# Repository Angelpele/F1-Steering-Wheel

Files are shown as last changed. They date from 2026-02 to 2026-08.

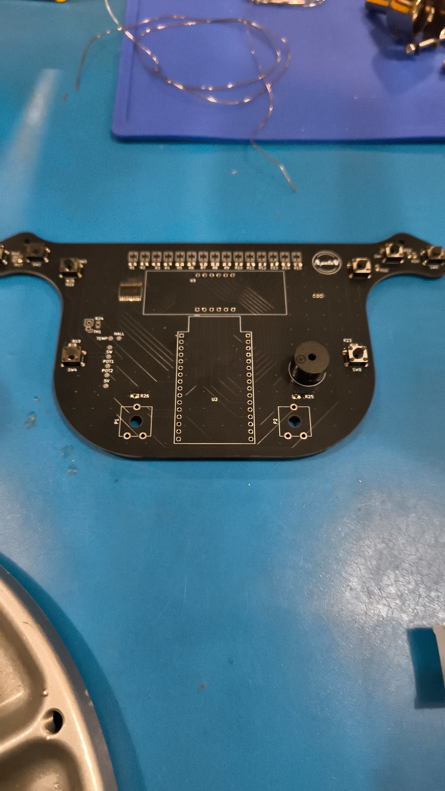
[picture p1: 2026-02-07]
Media/IMG-20260202-WA0003.jpeg

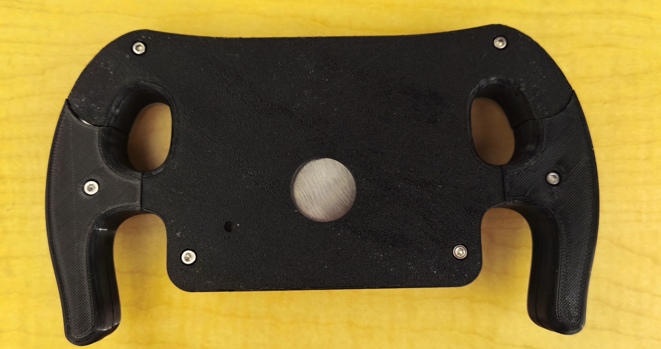
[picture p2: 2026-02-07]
Media/MVIMG_20260207_000938.jpg

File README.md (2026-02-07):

# 🏎️ F1 Steering Wheel

This project is a **custom-made F1-style steering wheel** designed and built entirely from scratch, featuring a **custom PCB**, advanced input/output handling, and a rigid mechanical structure optimized for sim racing or small racing karts.

<p align="center">
  
</p>

---

## 🛠️ Electronics & PCB Design

The steering wheel is built around a **custom-designed PCB** using an **ESP32-C6 DevKitC-1** as the main controller, providing high performance and wireless capabilities.

### Main Electronic Features

| Component | Description |
|---|---|
| **ESP32-C6 DevKitC-1** | Main microcontroller handling inputs, logic, and communication |
| **74LS154 Decoder** | 4-to-16 line decoder used to drive LED array |
| **15 LEDs (RGB Groups)** | Divided into 3 groups of 5 LEDs (Green, Red, Blue) |
| **4-Digit 7-Segment Display** | Displays speed, gear, or system information |
| **8 Buttons (Resistor Ladder)** | All buttons read through a single ADC pin |
| **2 Potentiometers** | Center mounted, using voltage divider for analog input |
| **Buzzer** | Return sound feedback to the user reacting to different variables |
| **External Sensor Support** | Designed for external NTC temperature sensor and Hall-effect sensor inputs|
| **Custom Buttons PCB** | Top-mounted buttons integrated into the housing |

<p align="center">
  
</p>

The **15 LEDs**, controlled via the **74LS154 decoder**, provide real-time visual feedback:
- **Green LEDs** → Speed or system status  
- **Red LEDs** → Engine RPM / rev-up indication  
- **Blue LEDs** → Custom functions or gear indicators  

The decoder uses **4 control lines** to efficiently manage all LED outputs.

The **8 buttons** are arranged with a resistor ladder configuration, reading all the possible values with an ADC converter (analog input).

📄 Find the **Circuit Schematic** right below:

<p align="center">
  <a href="Hardware/Volante Maquinillo.pdf">
    Electronics Schematic
  </a>
</p>

---

## ⚙️ Mechanical Design

The entire mechanical structure was **designed from scratch in Fusion 360**, prioritizing rigidity, modularity, and professional finish.

<p align="center">
  
</p>

### Structural Overview

1. **Lower Case**
   - Houses most electronic components.
   - Rear sockets allow bolts to be inserted flush with the surface.
   - Enables clean and solid assembly.

2. **Steel Reinforcement Plate**
   - Water-jet cut steel middle plate.
   - Provides structural rigidity and torsional strength.
   - Acts as the main load-bearing core.

3. **TPU Handles**
   - Designed in **two parts per side**.
   - Bolted directly to the internal steel structure.
   - Flexible yet durable for comfortable grip.

4. **PCB Mounting**
   - Custom PCB is mounted on top of the steel plate.
   - Electrically isolated to prevent short circuits.
   - Secured using threaded inserts.

5. **Top Case & Buttons**
   - Top enclosure holds the custom-made buttons.
   - Assembled using **threaded inserts melted into the plastic**.
   - All components are bolted together for maximum durability.

---

## 🚀 Project Goals

- Realistic **F1-style input device**
- Robust **mechanical and electrical integration**
- Support for additional external sensors
- Internal steel structure for proper soldering to external axes

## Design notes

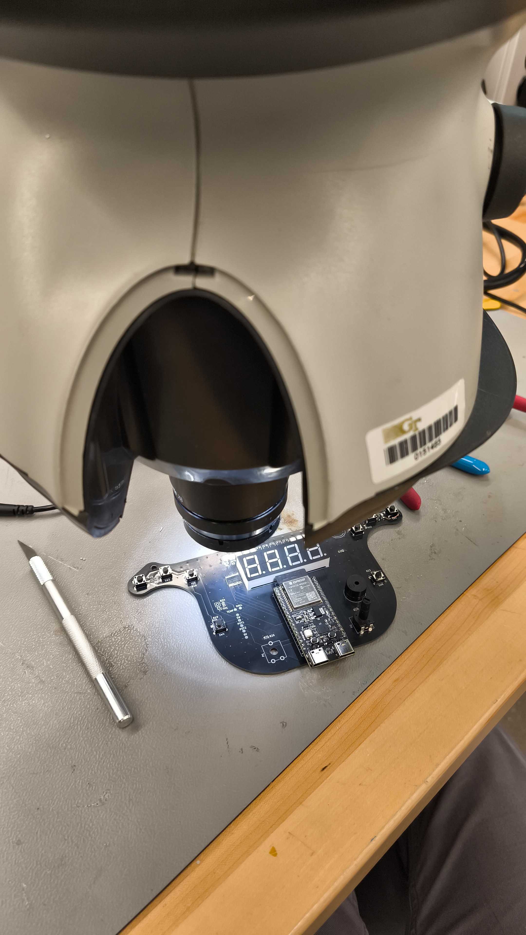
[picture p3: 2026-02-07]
Media/IMG-20260206-WA0000.jpeg

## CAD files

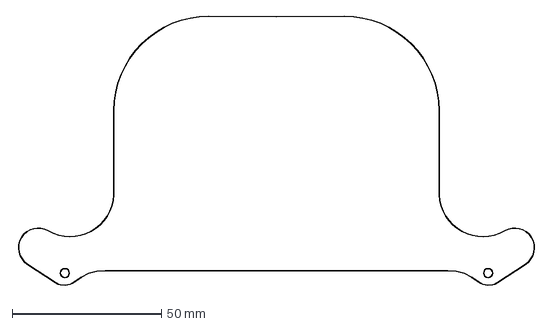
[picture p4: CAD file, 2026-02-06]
Mechanical/Main_DXF.dxf
174.4 x 90.5 mm

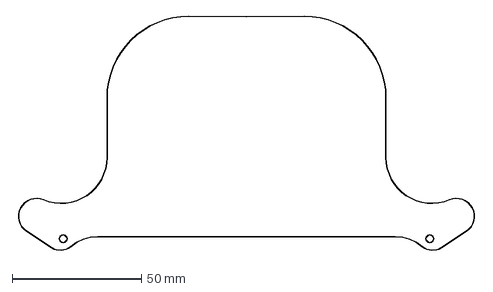
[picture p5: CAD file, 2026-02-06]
Mechanical/Main_PCB.dxf
177.8 x 90.9 mm

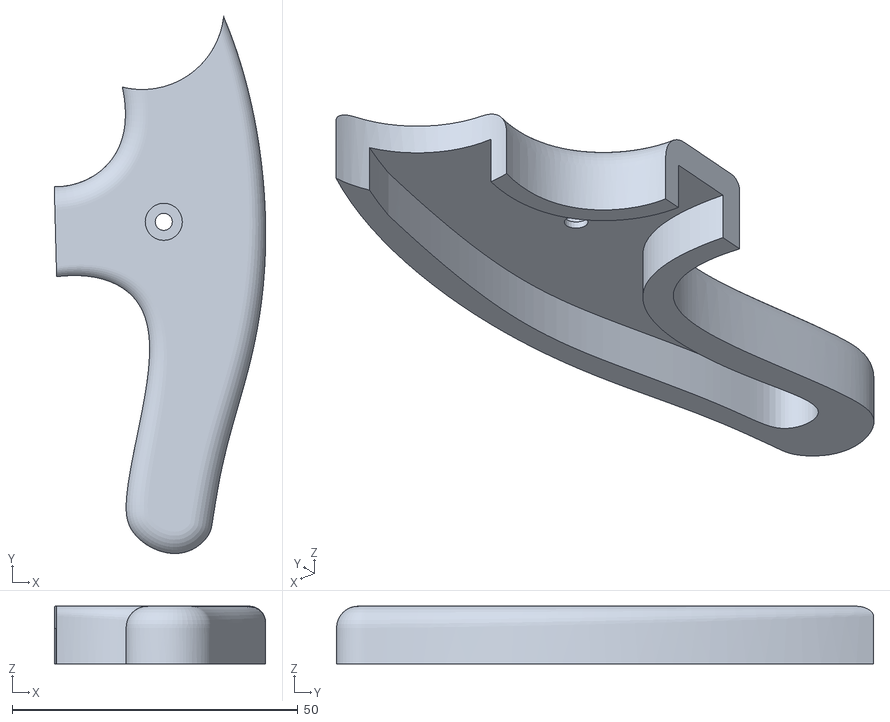
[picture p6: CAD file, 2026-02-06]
Mechanical/Left_Grip_Inf.stl
37.0 x 94.0 x 10.1

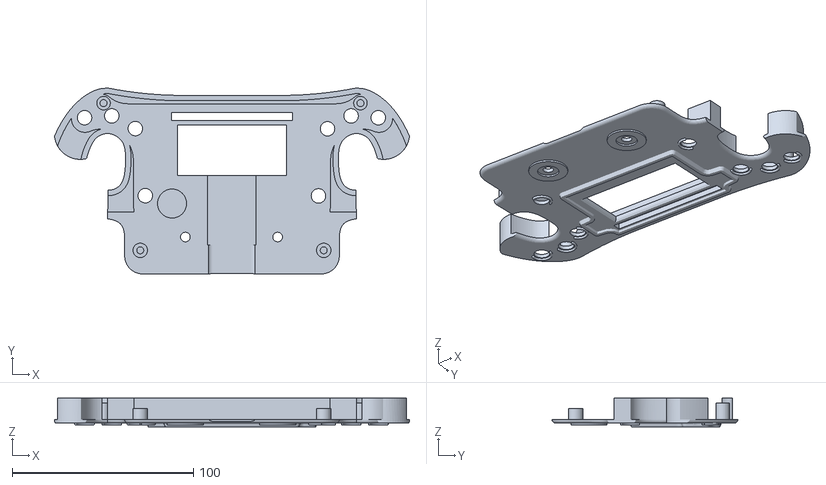
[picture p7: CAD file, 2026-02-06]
Mechanical/Top_Case.stl
195.8 x 102.5 x 15.8

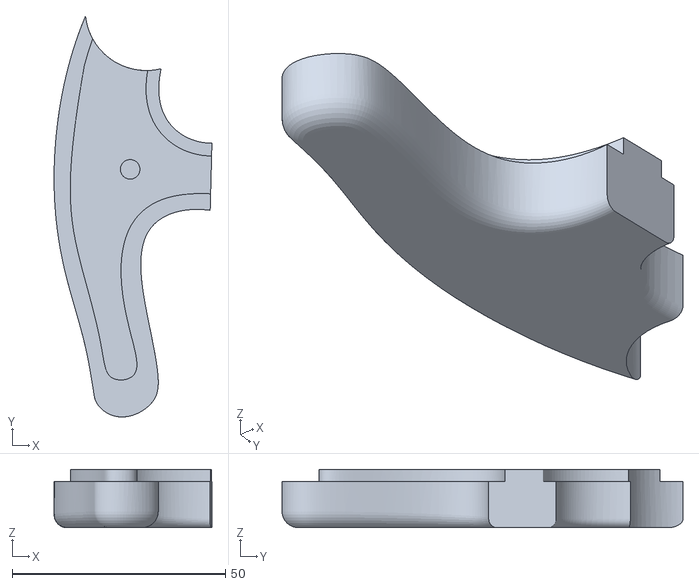
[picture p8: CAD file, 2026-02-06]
Mechanical/Right_Grip_Sup.stl
37.0 x 94.0 x 13.7

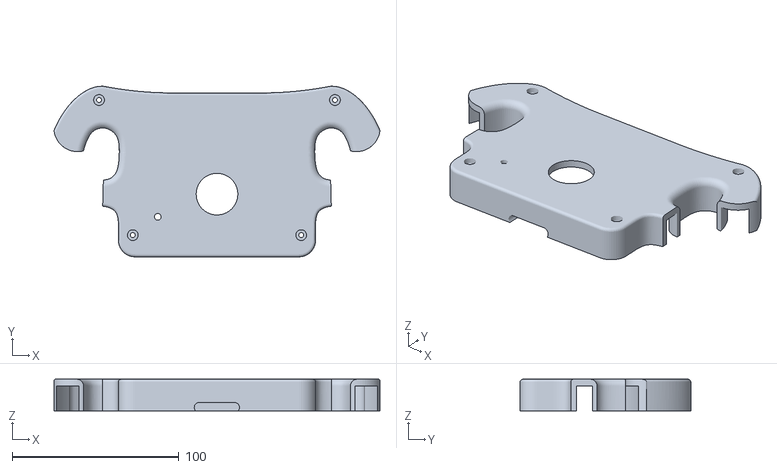
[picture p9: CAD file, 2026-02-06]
Mechanical/Bottom_Case.stl
195.8 x 102.5 x 19.0

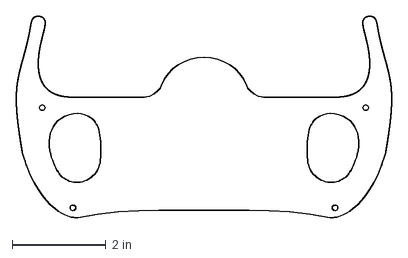
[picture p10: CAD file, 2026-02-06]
Mechanical/Al_Struct.dxf
7.99 x 4.29 in

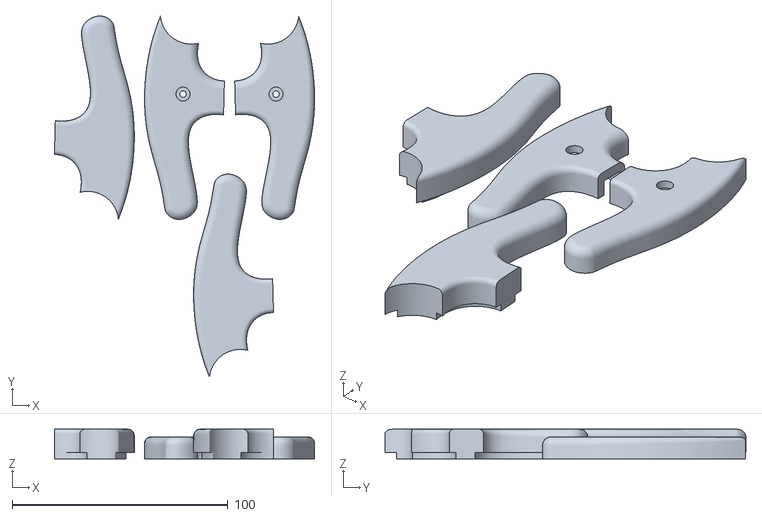
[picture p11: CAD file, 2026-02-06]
Mechanical/Grips.stl
120.5 x 167.2 x 13.7

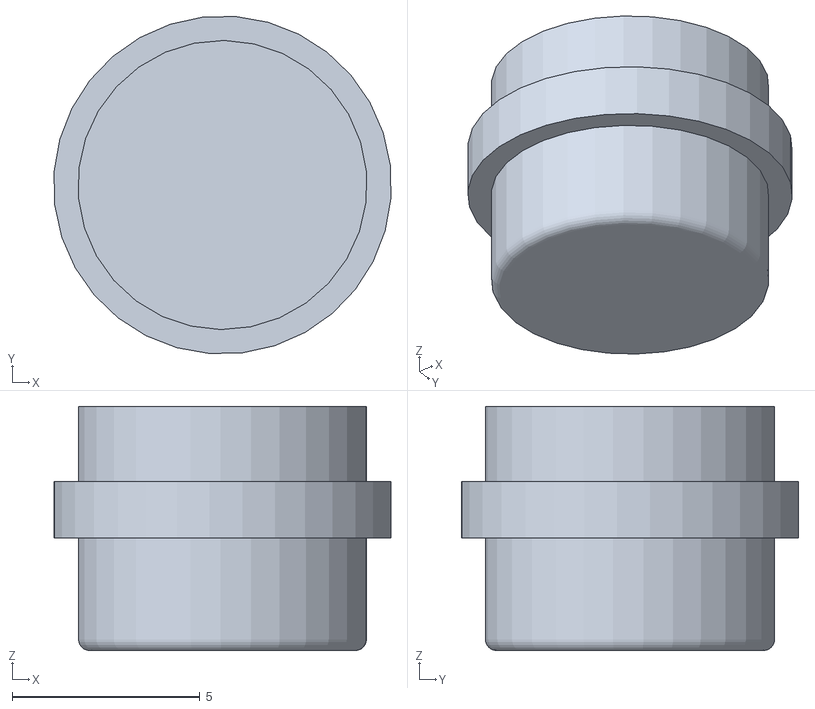
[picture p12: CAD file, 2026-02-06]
Mechanical/Button.stl
8.97 x 8.97 x 6.50

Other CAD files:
Mechanical/Left_Grip_Sup.stl
Mechanical/Right_Grip_Inf.stl

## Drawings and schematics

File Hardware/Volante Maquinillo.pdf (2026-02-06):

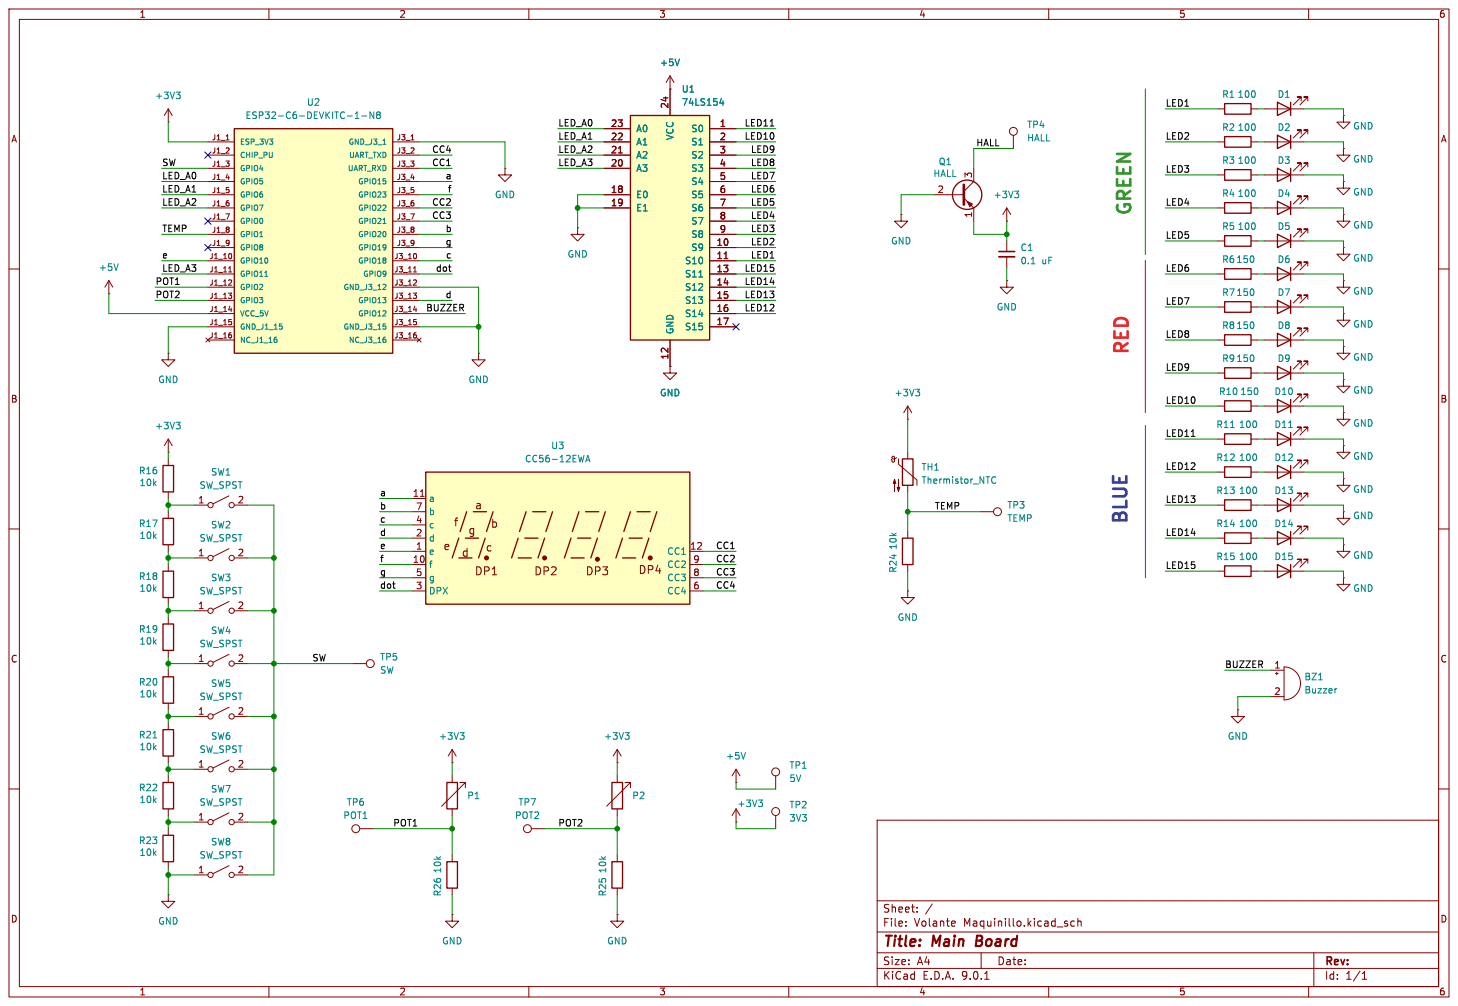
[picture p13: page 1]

Id: 1/1 Title: Main Board

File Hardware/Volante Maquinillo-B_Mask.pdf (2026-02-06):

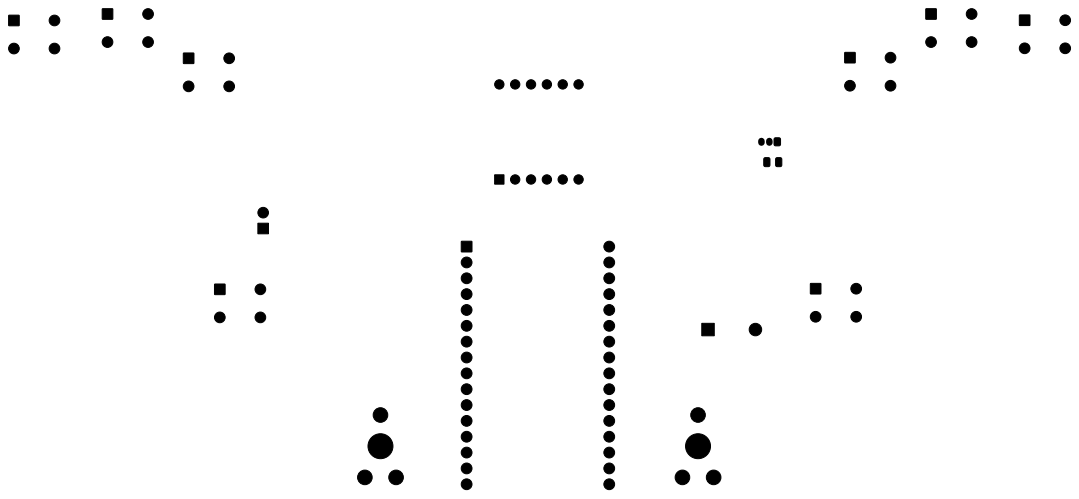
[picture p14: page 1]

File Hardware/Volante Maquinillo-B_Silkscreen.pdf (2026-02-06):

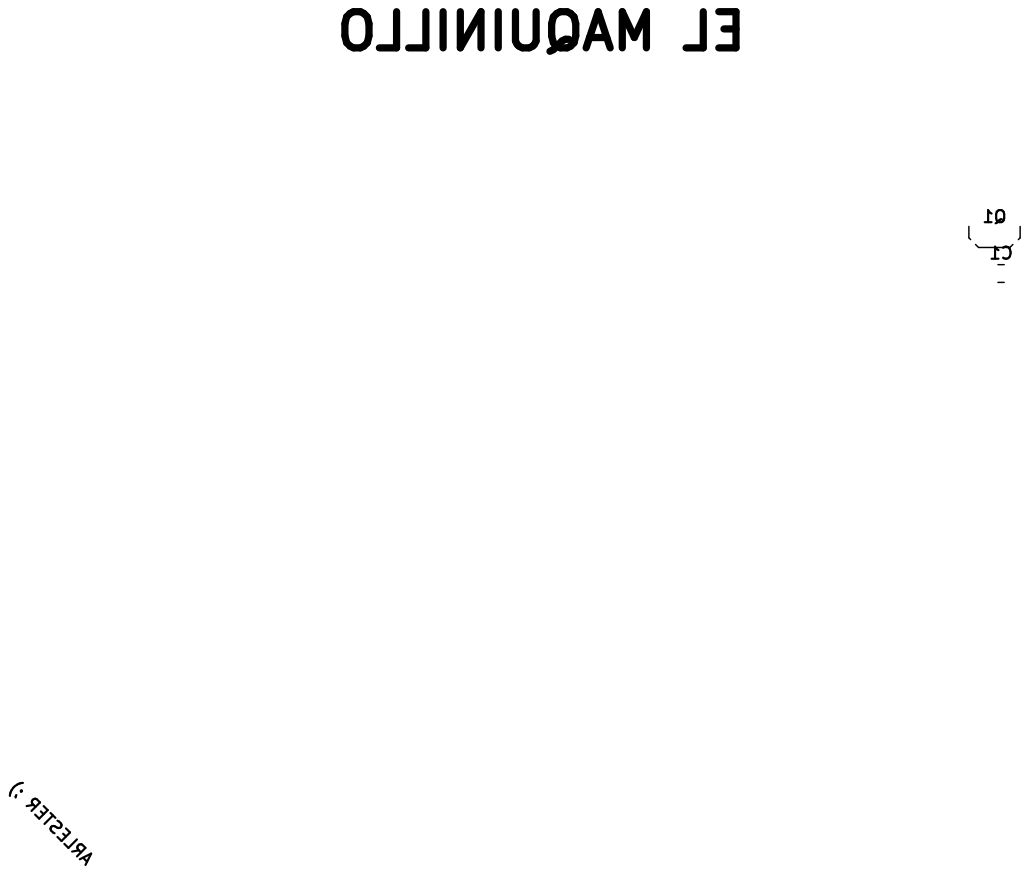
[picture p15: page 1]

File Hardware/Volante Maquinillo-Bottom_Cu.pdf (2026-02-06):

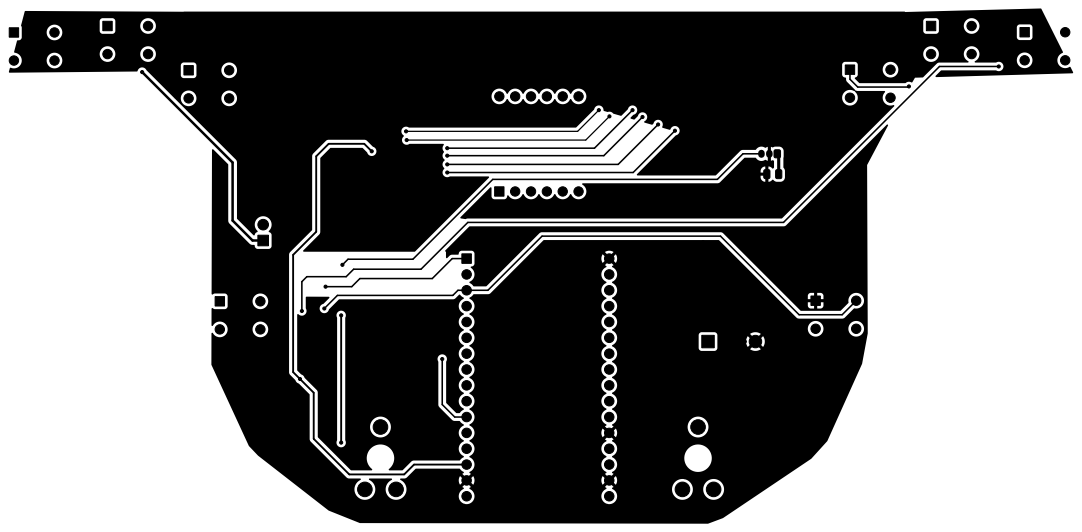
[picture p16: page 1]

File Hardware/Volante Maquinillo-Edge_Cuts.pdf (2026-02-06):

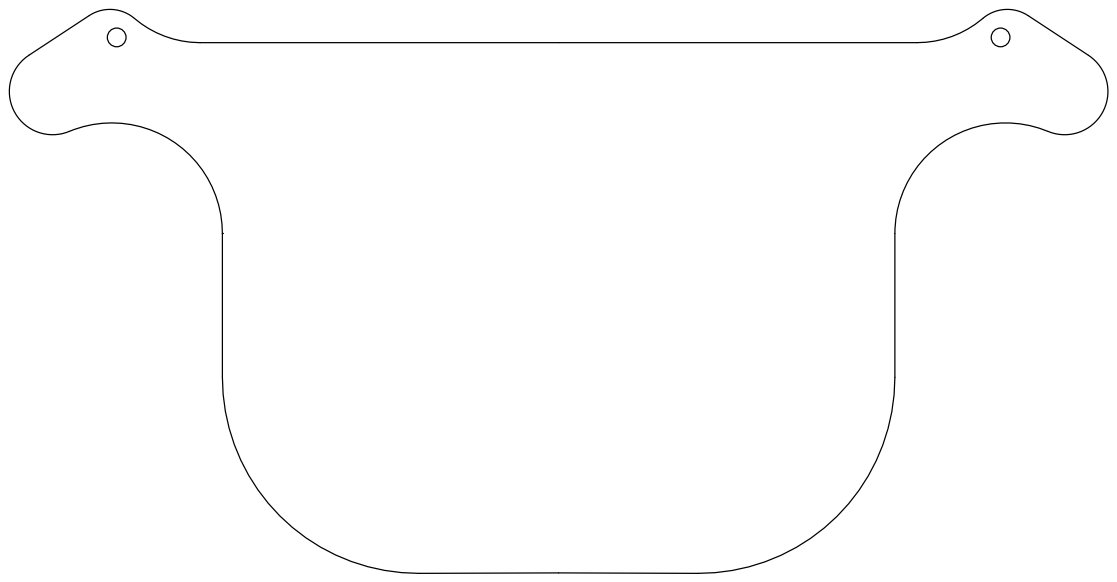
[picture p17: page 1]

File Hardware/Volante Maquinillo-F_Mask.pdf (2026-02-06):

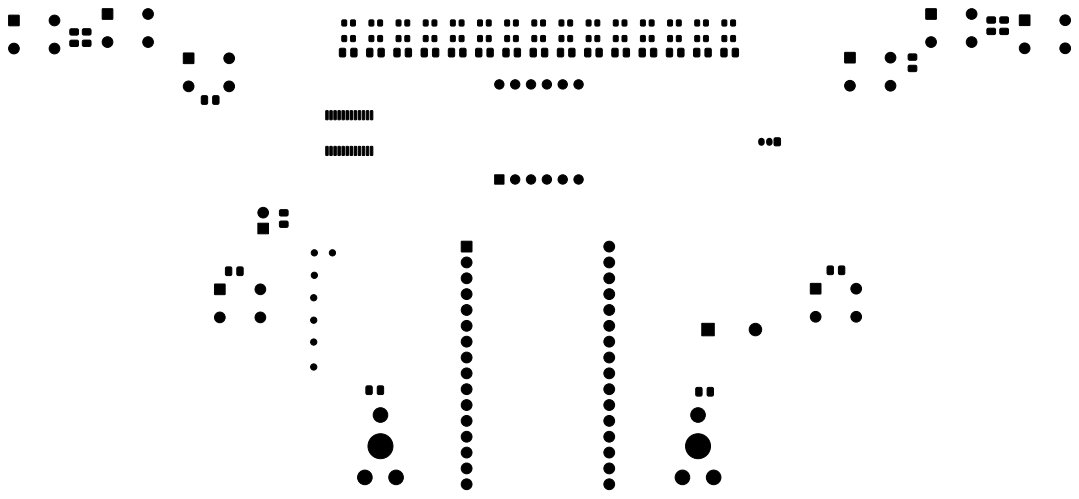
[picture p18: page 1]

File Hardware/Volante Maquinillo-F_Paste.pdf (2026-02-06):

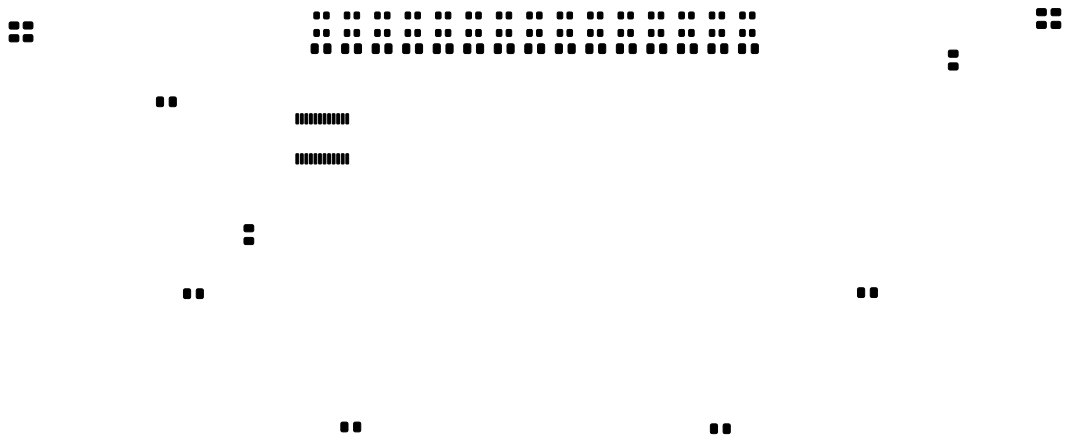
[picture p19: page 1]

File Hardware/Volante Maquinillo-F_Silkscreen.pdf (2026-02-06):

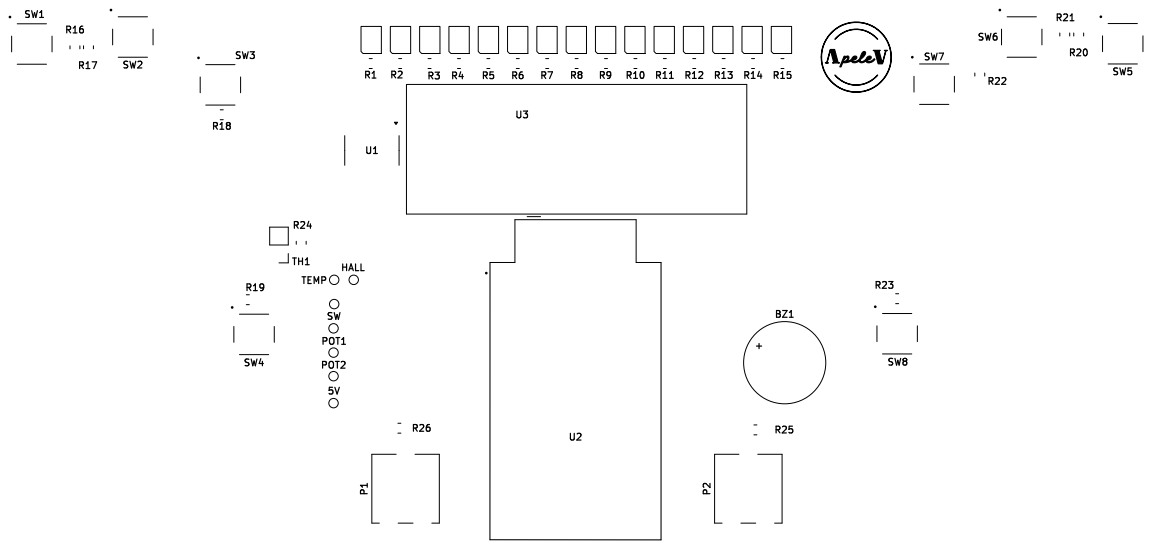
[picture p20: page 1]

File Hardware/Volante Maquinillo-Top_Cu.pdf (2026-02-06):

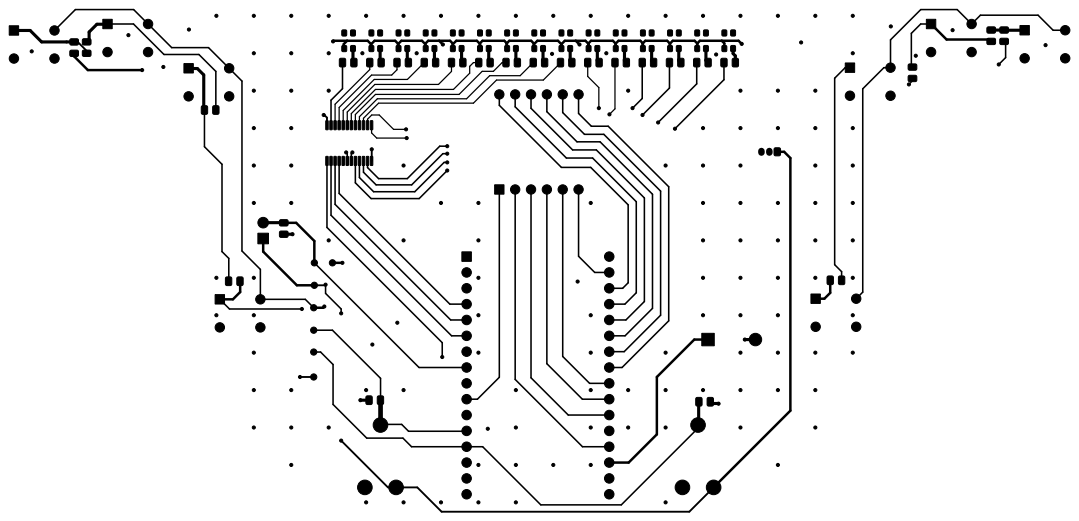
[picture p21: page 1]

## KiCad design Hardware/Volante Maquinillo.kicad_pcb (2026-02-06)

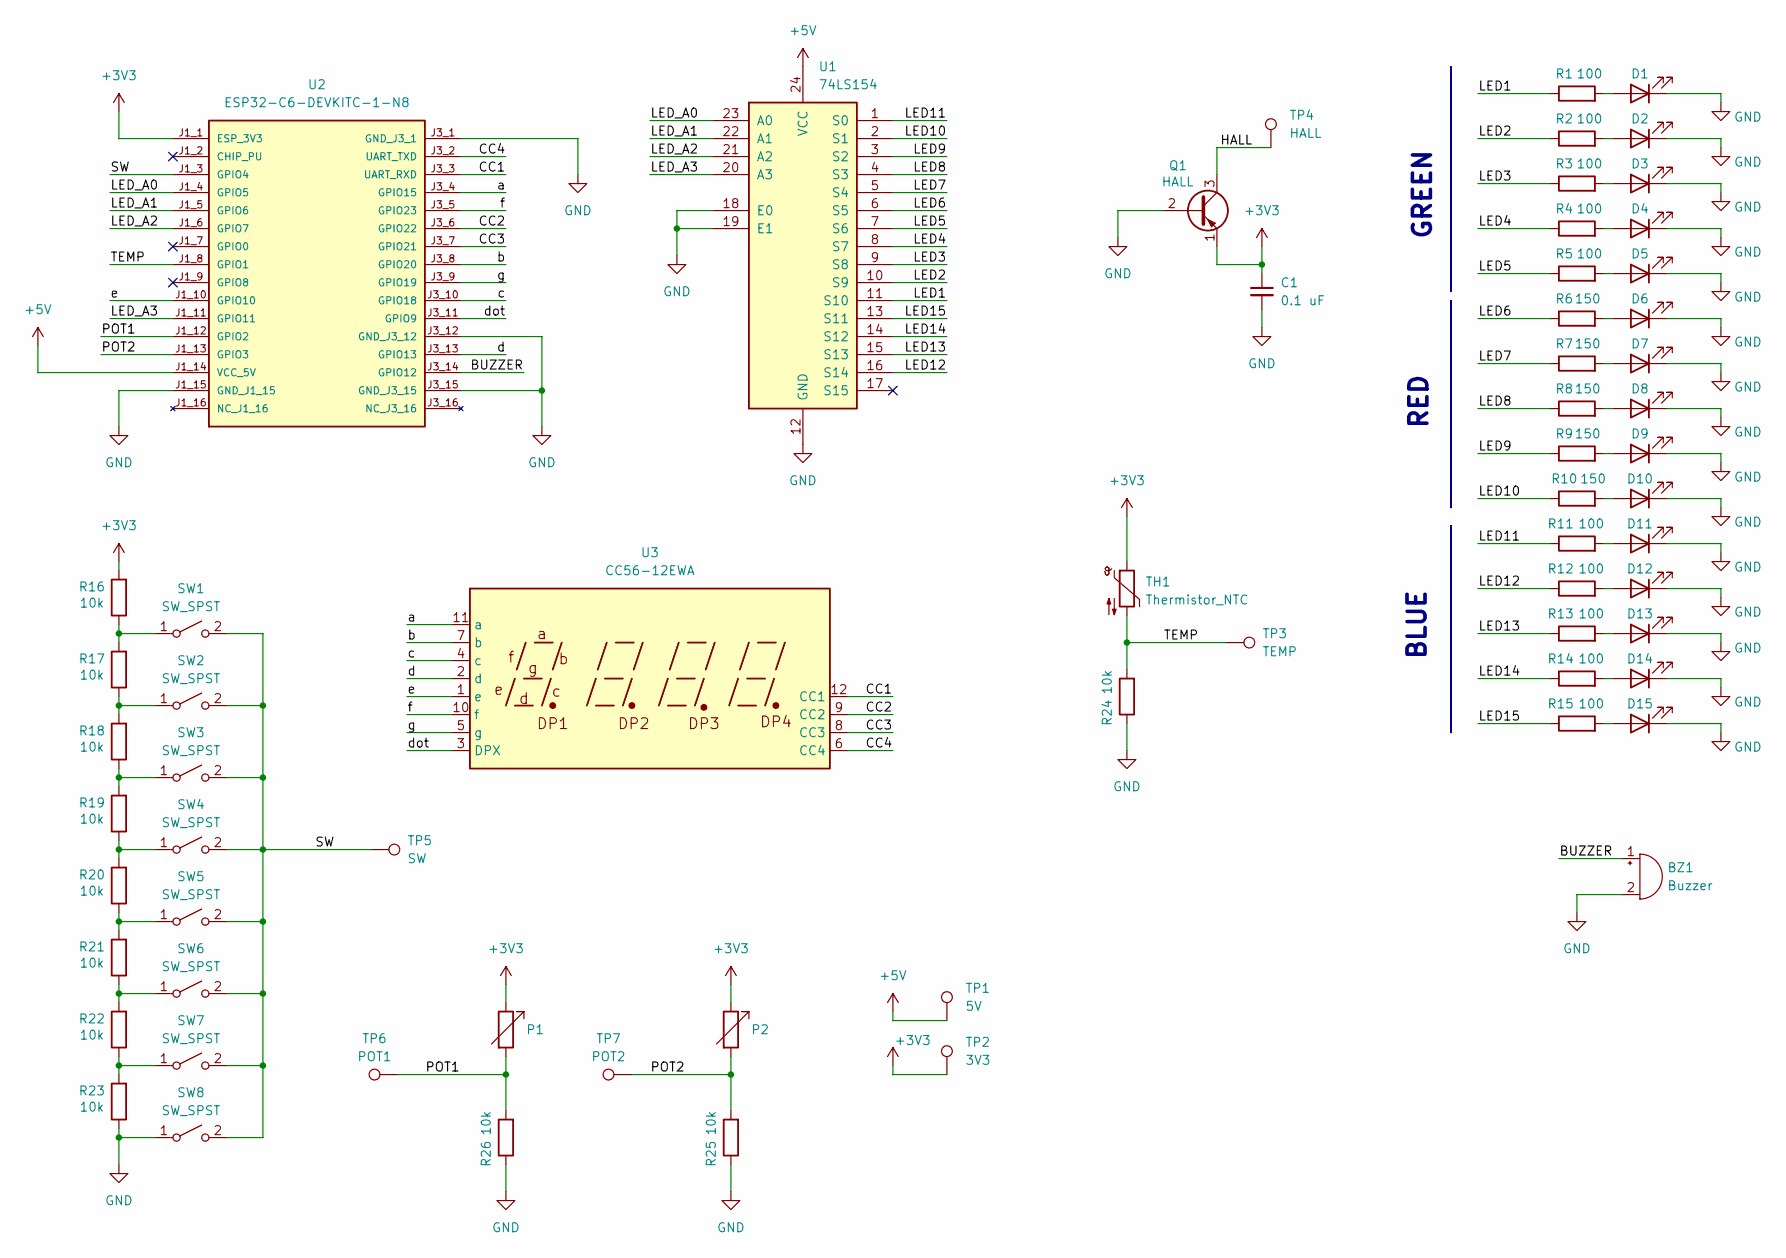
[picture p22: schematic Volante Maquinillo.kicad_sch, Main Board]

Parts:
BZ1: Buzzer; Buzzer_12x9.5RM7.6
C1: 0.1 uF; C_0805_2012Metric
D1, D2, D3, D4, D5, D6, D7, D8, D9, D10, D11, D12, D13, D14, D15: LED; LED_Cree-PLCC4_3.2x2.8mm_CCW
P1, P2: R_Variable; Potentiometer_ACP_CA9-V10_Vertical_Hole
Q1: HALL; TO-92Flat
R1, R2, R3, R4, R5, R11, R12, R13, R14, R15: 100; R_0805_2012Metric
R6, R7, R8, R9, R10: 150; R_0805_2012Metric
R16, R17, R18, R19, R20, R21, R22, R23, R24, R25, R26: 10k; R_0805_2012Metric
SW1, SW2, SW3, SW4, SW5, SW6, SW7, SW8: SW_SPST; SW_TS02-66-60-BK-100-LCR-D
TH1: Thermistor_NTC; PinHeader_1x02_P2.54mm_Vertical
TP1: 5V; TestPoint_Pad_D1.0mm
TP2: 3V3; TestPoint_Pad_D1.0mm
TP3: TEMP; TestPoint_Pad_D1.0mm
TP4: HALL; TestPoint_Pad_D1.0mm
TP5: SW; TestPoint_Pad_D1.0mm
TP6: POT1; TestPoint_Pad_D1.0mm
TP7: POT2; TestPoint_Pad_D1.0mm
U1: 74LS154; TSSOP-24_4.4x7.8mm_P0.65mm
U2: ESP32-C6-DEVKITC-1-N8; MODULE_ESP32-C6-DEVKITC-1-N8; PARTREV 1.3
U3: CC56-12EWA; CA56-12EWA

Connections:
+3V3: C1.1, P1.1, P2.1, Q1.1 (E), R16.2, TH1.1, TP2.1, U2.J1_1 (ESP_3V3)
+5V: TP1.1, U1.24 (VCC), U2.J1_14 (VCC_5V)
/BUZZER: BZ1.1 (+), U2.J3_14 (GPIO12)
/CC1: U2.J3_3 (UART_RXD), U3.12 (CC1)
/CC2: U2.J3_6 (GPIO22), U3.9 (CC2)
/CC3: U2.J3_7 (GPIO21), U3.8 (CC3)
/CC4: U2.J3_2 (UART_TXD), U3.6 (CC4)
/HALL: Q1.3 (C), TP4.1
/LED1: R1.1, U1.11 (S10)
/LED2: R2.1, U1.10 (S9)
/LED3: R3.1, U1.9 (S8)
/LED4: R4.1, U1.8 (S7)
/LED5: R5.1, U1.7 (S6)
/LED6: R6.1, U1.6 (S5)
/LED7: R7.1, U1.5 (S4)
/LED8: R8.1, U1.4 (S3)
/LED9: R9.1, U1.3 (S2)
/LED10: R10.1, U1.2 (S1)
/LED11: R11.1, U1.1 (S0)
/LED12: R12.1, U1.16 (S14)
/LED13: R13.1, U1.15 (S13)
/LED14: R14.1, U1.14 (S12)
/LED15: R15.1, U1.13 (S11)
/LED_A0: U1.23 (A0), U2.J1_4 (GPIO5)
/LED_A1: U1.22 (A1), U2.J1_5 (GPIO6)
/LED_A2: U1.21 (A2), U2.J1_6 (GPIO7)
/LED_A3: U1.20 (A3), U2.J1_11 (GPIO11)
/POT1: P1.2, R26.2, TP6.1, U2.J1_12 (GPIO2)
/POT2: P2.2, R25.2, TP7.1, U2.J1_13 (GPIO3)
/SW: SW1.2 (B), SW2.2 (B), SW3.2 (B), SW4.2 (B), SW5.2 (B), SW6.2 (B), SW7.2 (B), SW8.2 (B), TP5.1, U2.J1_3 (GPIO4)
/TEMP: R24.2, TH1.2, TP3.1, U2.J1_8 (GPIO1)
/a: U2.J3_4 (GPIO15), U3.11 (a)
/b: U2.J3_8 (GPIO20), U3.7 (b)
/c: U2.J3_10 (GPIO18), U3.4 (c)
/d: U2.J3_13 (GPIO13), U3.2 (d)
/dot: U2.J3_11 (GPIO9), U3.3 (DPX)
/e: U2.J1_10 (GPIO10), U3.1 (e)
/f: U2.J3_5 (GPIO23), U3.10 (f)
/g: U2.J3_9 (GPIO19), U3.5 (g)
GND: BZ1.2 (-), C1.2, D1.1 (K), D2.1 (K), D3.1 (K), D4.1 (K), D5.1 (K), D6.1 (K), D7.1 (K), D8.1 (K), D9.1 (K), D10.1 (K), D11.1 (K), D12.1 (K), D13.1 (K), D14.1 (K), D15.1 (K), Q1.2 (B), R23.1, R24.1, R25.1, R26.1, SW8.1 (A), U1.12 (GND), U1.18 (E0), U1.19 (E1), U2.J1_15 (GND_J1_15), U2.J3_1 (GND_J3_1), U2.J3_12 (GND_J3_12), U2.J3_15 (GND_J3_15)
unnamed: D1.2 (A), R1.2
unnamed: D2.2 (A), R2.2
unnamed: D3.2 (A), R3.2
unnamed: D4.2 (A), R4.2
unnamed: D5.2 (A), R5.2
unnamed: D6.2 (A), R6.2
unnamed: D7.2 (A), R7.2
unnamed: D8.2 (A), R8.2
unnamed: D9.2 (A), R9.2
unnamed: D10.2 (A), R10.2
unnamed: D11.2 (A), R11.2
unnamed: D12.2 (A), R12.2
unnamed: D13.2 (A), R13.2
unnamed: D14.2 (A), R14.2
unnamed: D15.2 (A), R15.2
unnamed: R16.1, R17.2, SW1.1 (A)
unnamed: R17.1, R18.2, SW2.1 (A)
unnamed: R18.1, R19.2, SW3.1 (A)
unnamed: R19.1, R20.2, SW4.1 (A)
unnamed: R20.1, R21.2, SW5.1 (A)
unnamed: R21.1, R22.2, SW6.1 (A)
unnamed: R22.1, R23.2, SW7.1 (A)

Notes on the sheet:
RED
BLUE
GREEN

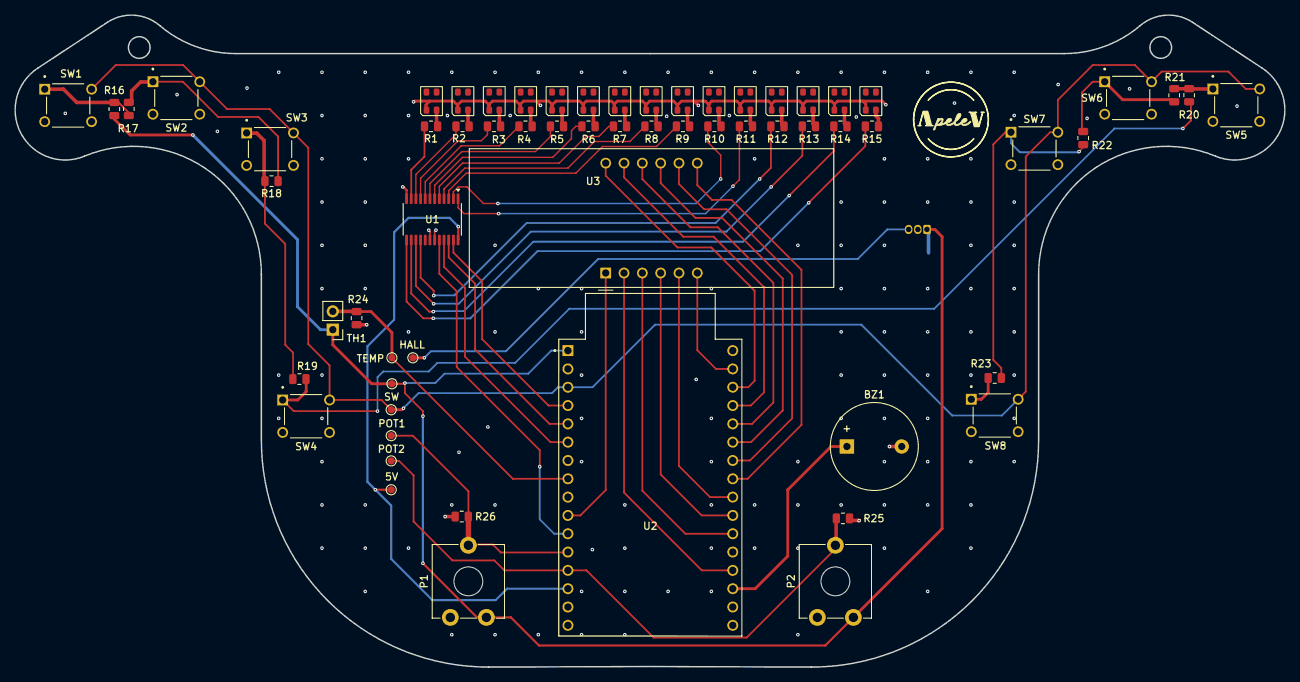
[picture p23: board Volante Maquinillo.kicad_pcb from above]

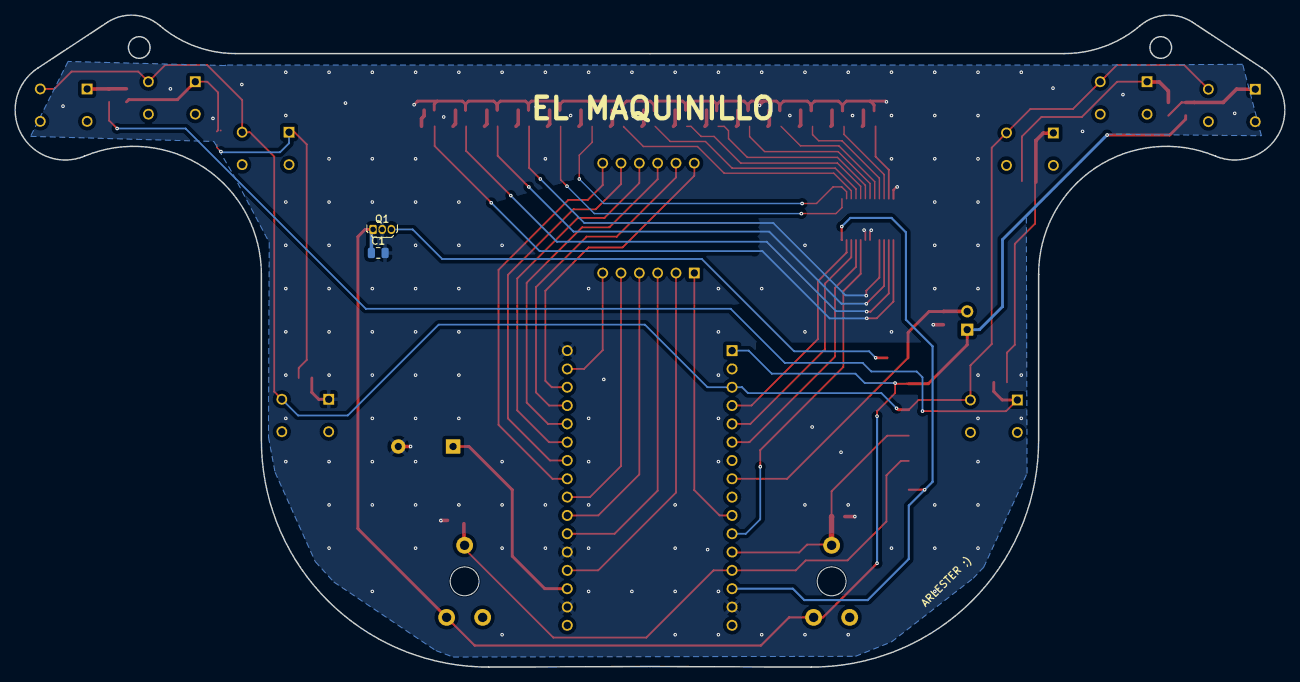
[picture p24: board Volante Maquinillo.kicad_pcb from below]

Board: 2 copper layers, 176.1 x 90.4 mm, 65 parts (2 on the bottom side), 62 nets.

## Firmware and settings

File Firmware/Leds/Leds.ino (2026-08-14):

// 74LS154 address pins
const int addrPins[4] = {5, 6, 7, 11};

// LED pattern (values 0–15 correspond to outputs Y0–Y15)
int pattern[] = {0, 1, 2, 3, 4, 5, 6, 7,
                 8, 9, 10, 11, 12, 13, 14, 15};

int patternLength = sizeof(pattern) / sizeof(pattern[0]);

void setup() {
  for (int i = 0; i < 4; i++) {
    pinMode(addrPins[i], OUTPUT);
  }
}

void selectOutput(int value) {
  for (int i = 0; i < 4; i++) {
    digitalWrite(addrPins[i], (value >> i) & 0x01);
  }
}

// Multiplex all LEDs ON for a given time (ms)
void allLedsOn(int duration_ms) {
  unsigned long start = millis();
  while (millis() - start < duration_ms) {
    for (int i = 0; i < 16; i++) {
      selectOutput(i);
      delayMicroseconds(500);  // escaneo rápido
    }
  }
}

// Turn all LEDs OFF
void allLedsOff(int duration_ms) {
  delay(duration_ms);
}

void loop() {

  // Forward pattern
  for (int i = 0; i < patternLength; i++) {
    selectOutput(pattern[i]);
    delay(100);
  }

  // Reverse pattern
  for (int i = patternLength - 1; i >= 0; i--) {
    selectOutput(pattern[i]);
    delay(100);
  }

  // Blink all LEDs 3 times (100 ms ON / 100 ms OFF)
  for (int i = 0; i < 3; i++) {
    allLedsOn(500);
    allLedsOff(500);
  }
}

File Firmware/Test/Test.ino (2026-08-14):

// ================= 74LS154 =================
const int addrPins[4] = {5, 6, 7, 11};

int pattern[] = {0, 1, 2, 3, 4, 5, 6, 7,
                 8, 9, 10, 11, 12, 13, 14, 15};
int patternLength = sizeof(pattern) / sizeof(pattern[0]);

// ================= ADC =================
const int buttonsPin = 4;

// ================= DISPLAY 7 SEG =================
// Segments
const int segA = 15;
const int segB = 20;
const int segC = 18;
const int segD = 13;
const int segE = 10;
const int segF = 23;
const int segG = 19;

// Digits (common cathode)
const int dig1 = 17;
const int dig2 = 22;
const int dig3 = 21;
const int dig4 = 16;

const int segPins[7] = {segA, segB, segC, segD, segE, segF, segG};
const int digPins[4] = {dig1, dig2, dig3, dig4};

// a b c d e f g
const byte numbers[10][7] = {
  {1,1,1,1,1,1,0},
  {0,1,1,0,0,0,0},
  {1,1,0,1,1,0,1},
  {1,1,1,1,0,0,1},
  {0,1,1,0,0,1,1},
  {1,0,1,1,0,1,1},
  {1,0,1,1,1,1,1},
  {1,1,1,0,0,0,0},
  {1,1,1,1,1,1,1},
  {1,1,1,1,0,1,1}
};

// ================= SETUP =================
void setup() {
  pinMode(buttonsPin, INPUT);

  for (int i = 0; i < 4; i++) pinMode(addrPins[i], OUTPUT);
  for (int i = 0; i < 7; i++) pinMode(segPins[i], OUTPUT);
  for (int i = 0; i < 4; i++) pinMode(digPins[i], OUTPUT);
}

// ================= 74LS154 FUNCTIONS =================
void selectOutput(int value) {
  for (int i = 0; i < 4; i++) {
    digitalWrite(addrPins[i], (value >> i) & 0x01);
  }
}

void allLedsOn(int duration_ms) {
  unsigned long start = millis();
  while (millis() - start < duration_ms) {
    for (int i = 0; i < 16; i++) {
      selectOutput(i);
      delayMicroseconds(500);
    }
  }
}

// ================= DISPLAY FUNCTIONS =================
void mostrarNumero(int num) {
  int digits[4];

  digits[0] = (num / 1000) % 10;
  digits[1] = (num / 100)  % 10;
  digits[2] = (num / 10)   % 10;
  digits[3] = num % 10;

  for (int i = 0; i < 4; i++) {
    activarDigito(i);
    mostrarDigito(digits[i]);
    delay(1);
    apagarDigitos();
  }
}

void mostrarDigito(int n) {
  for (int i = 0; i < 7; i++) {
    digitalWrite(segPins[i], numbers[n][i]);
  }
}

void activarDigito(int d) {
  apagarDigitos();
  digitalWrite(digPins[d], LOW);
}

void apagarDigitos() {
  for (int i = 0; i < 4; i++) {
    digitalWrite(digPins[i], HIGH);
  }
}

// ================= LOOP =================
void loop() {

  // --- LED Forward pattern ---
  for (int i = 0; i < patternLength; i++) {
    selectOutput(pattern[i]);
    delay(10);
  }

  // --- LED Reverse pattern ---
  for (int i = patternLength - 1; i >= 0; i--) {
    selectOutput(pattern[i]);
    delay(100);
  }

  // --- Blink all LEDs visually ---
  for (int i = 0; i < 3; i++) {
    allLedsOn(500);
    delay(500);
  }

  // --- Read ADC and display RAW value ---
  int adcValue = analogRead(buttonsPin);

  for (int i = 0; i < 50; i++) {   // refresh display for visibility
    mostrarNumero(adcValue);
  }
}

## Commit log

2026-02-07 README update
    Expanded README to include detailed project description, electronics and PCB design, mechanical design, user interface, project goals, and future improvements.
2026-02-07 Include SCH README
    Added a section for the Circuit Schematic with a link and image.
